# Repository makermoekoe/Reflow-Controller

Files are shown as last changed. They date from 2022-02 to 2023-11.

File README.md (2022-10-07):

# Reflow-Controller

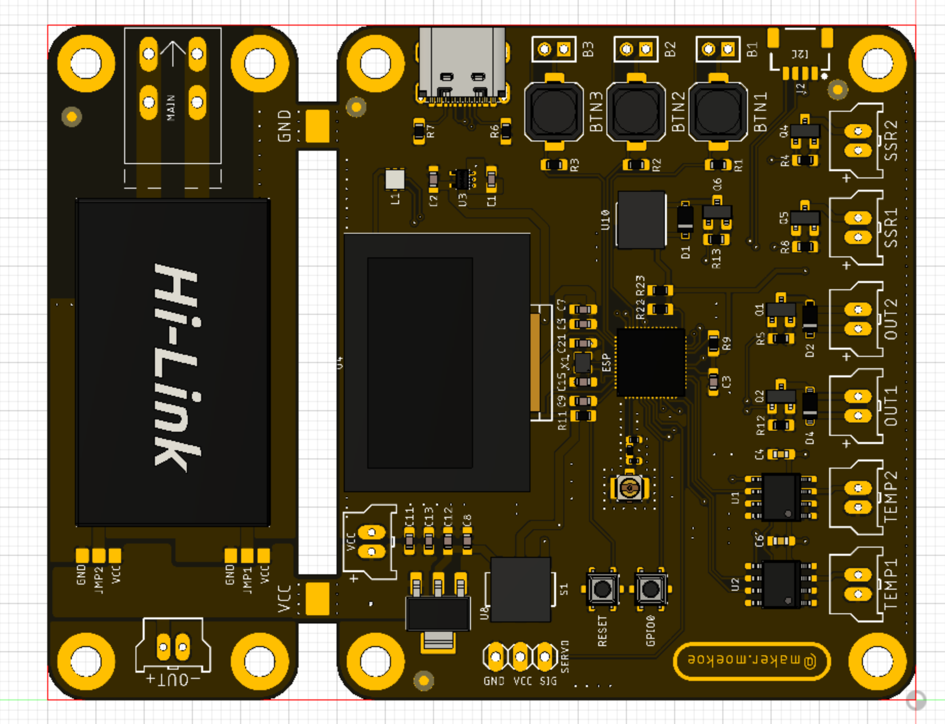
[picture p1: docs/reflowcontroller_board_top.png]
</a>

The Reflow-Controller was built to control different kinds of reflow ovens, hotplates and whatever is coming to my mind in the future. It is based on the ESP32-S2 ([datasheet](https://www.espressif.com/sites/default/files/documentation/esp32-s2_datasheet_en.pdf)) and thus can be programmed to be used with a WiFi App or whatever. Nevertheless, it has an onboard OLED display and three buttons included to be used as a standalone solution either.

The [Youtube video](https://youtu.be/nffLDqJwJ3Q) shows the assembly of a complete reflow oven system and the first tests.

Features of the PCB:

- ESP32-S2 MCU
- 2x MAX6675 thermocouple sensor input
- 2x Fan output (inductive loads/flyback diodes included)
- 2x Solid state relay output
- 3x User button
- 1x APA102 user LED
- 1x Buzzer
- 1x Servo motor output
- 0,96" OLED display
- Optional ACDC converter (HLK-PM05, HLK-PM12) which can be separated if not used
- Optional I2C (QWIIC) connector

## GPIOs

The ESP32-S2 is connected like this:

Function | GPIO | Mode
-------- | -------- | --------
SSR1 | GPIO1 | Output
SSR2 | GPIO2 | Output
Servo | GPIO3 | Output
Fan1 | GPIO5 | Output
Fan2 | GPIO6 | Output
CLK | GPIO7 | SPI
MISO | GPIO9 | SPI
MOSI | GPIO11 | SPI
CS1 | GPIO12 | SPI
CS2 | GPIO13 | SPI
Buzzer | GPIO15 | Output
USB D- | GPIO19 | CDC
USB D+ | GPIO20 | CDC
SDA | GPIO33 | I2C
SCL | GPIO35 | I2C
Button1 | GPIO36 | Input
Button2 | GPIO39 | Input
Button3 | GPIO40 | Input
LED CLK | GPIO37 | LED
LED DATA | GPIO38 | LED
OLED RST | GPIO45 | Output

## ACDC power supply

The upper part of the PCB can be used as a power supply for the whole board as well as the higher voltage outputs (SSRs, Fans). If not used, it can be separated from the main board and may be used in another project where an ACDC adapter is needed.

The main board is equipped with an LM1117 3.3v voltage regulator which can be feed with 15v max. The output voltage of the ACDC power supply is the voltage for the SSR and the fan output channels. If you wanna use a servo motor in your project, make sure that the power supply has the correct voltage for the motor (probably 5v).

The HLK-PMXX module for the upper part of the PCB can be placed in two ways - on the bottom or on the top side. This gives the possibility to mount the whole PCB behind an acrylic glass (or whatever) so that the buttons as well as the OLED display are accessible. The two jumpers can then be used to select which signal is VCC and which one is GND. **Keep in mind that there are high voltage pins on the top side of the PCB when mounting the power supply on the bottom side! I've designed a 3D-printable cover, so that these pins cannot be touched accidentally. (Should be mounted in both cases)**

The board can also be powered via USB-C, but keep in mind that the output channels and the servo motor are not powered in this case (initially it is just available for flashing the board).

## Case & Spacer

As I wanna hide the whole PCB behind an acrylic glass (transparent) I've designed a simple case for the high voltage pins at the top and a spacer at the bottom of the PCB. In the end, the acrylic glass will be laser-cutted with some bridges for the buttons. Distance between PCB and acrylic glass is 5mm.

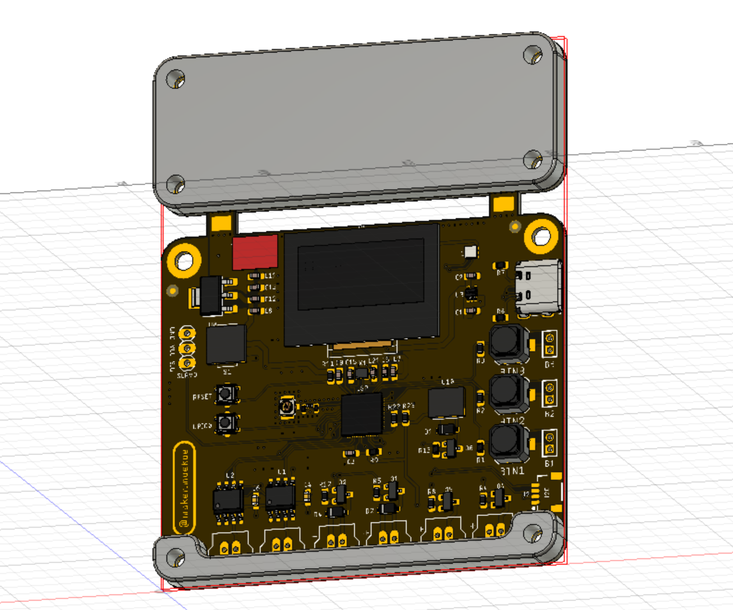
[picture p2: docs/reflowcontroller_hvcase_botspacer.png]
</a>

## Assembled reflow oven

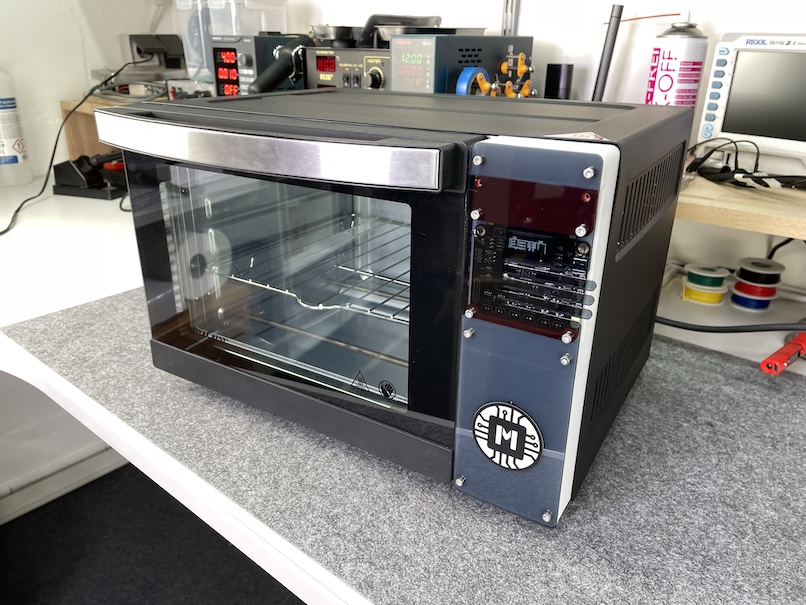
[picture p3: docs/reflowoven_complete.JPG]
</a>

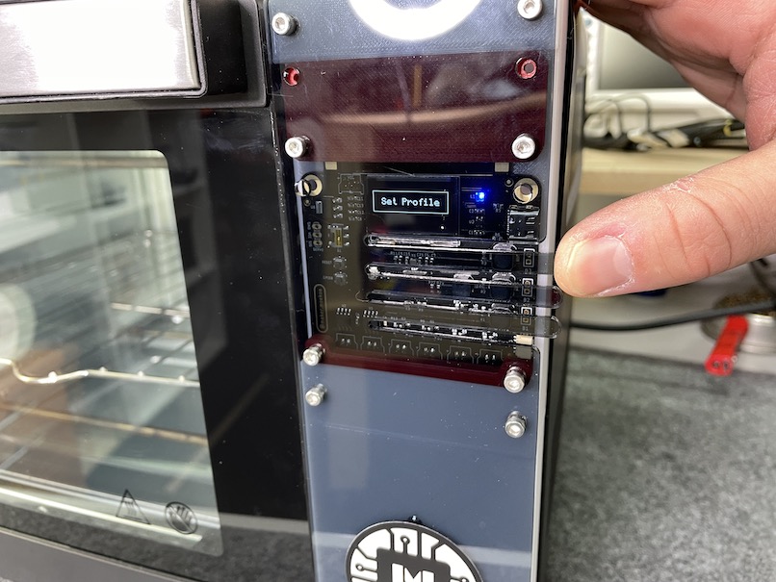
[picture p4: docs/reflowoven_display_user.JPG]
</a>

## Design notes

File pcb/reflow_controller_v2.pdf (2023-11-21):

Comment | Designator | Footprint | Device | Qty Description | Manufacturer | Mfr. Part No. | Supplier | supplier Part number
Connector | -OUT+,OUT1,OUT2,SSR1,SSR2,TEMP1,TEMP2,VCC MOLEX_2MM_2P | MOLEX_2MM_2P | 8 | Molex | 55935-0210 | 538-55935-0210
PIN HEADER | B1,B2,B3 | 1X02M | PINHD-1X02_2.00 | 3 PIN HEADER | XKB Connectivity | X4612WV-02I-C40D28 | LCSC | C2883055
PIN HEADER | SERVO | 1X03 | PINHD-1X03_2.54 | 1 PIN HEADER | XKB Connectivity | X6511WV-03H-C30D60 | LCSC | C706875
Connector | J2 | 1X04_1MM_RA | QWIIC_CONNECTORJS-1MM | 1 SparkFun I2C Standard Qwiic Connector SparkFun | PRT-16766 | Mouser | 474-PRT-16766
Connector | F2,F3 | R0402 | R-EU-0402-WOKEEPOUT | 2
0.1µF | C4,C6 | C0603 | C-EUC0603 | 2 CAPACITOR, European symbol YAGEO | CS0603KRX7R0BB104 | Mouser | 603-CS0603KRX70BB104
0.1µF | C3,C5,C9,C20 | C0603 | C-EU_WO_KEEPOUT | 4 | YAGEO | CS0603KRX7R0BB104 | Mouser | 603-CS0603KRX70BB104
0R-JUMPA | JMP1,JMP2 | A0R-JMP | 0R-JUMPA | 2 SMD 0R 0805 Jumper
10k | R1,R2,R3,R4,R5,R8,R9,R11,R12,R13,R20 | R0603 | R-EU_WO_KEEPOUT | 11 | Panasonic | ERJ-1RHD1002C | Mouser | 667-ERJ-1RHD1002C
10pF | C15,C21 | C0603 | C-EU_WO_KEEPOUT | 2 | YAGEO | CC0603FRNPO0BN100 | Mouser | 603-CC0603FR0BN100
10µF | C1,C7,C8,C13,C17,C18,C19 | C0603 | C-EU_WO_KEEPOUT | 7 | Samsung Electro-MechanicsCL10A106KQ8NNNC | Mouser | 187-CL10A106KQ8NNNC
1µF | C2,C11,C12 | C0603 | C-EU_WO_KEEPOUT | 3 | Taiyo Yuden | TMR107B7105KA-T | Mouser | 963-TMR107B7105KA-T
2.2µF | C14,C16 | C0603 | C-EU_WO_KEEPOUT | 2 | Murata Electronics | GRT188C71E225KE13D | Mouser | 81-GRT188C71E225KE3D
390k | R21 | R0603 | R-EU_WO_KEEPOUT | 1 | Panasonic | ERJ-1RHD3903C | Mouser | 667-ERJ-1RHD3903C
5.1k | R6,R7,R22,R23 | R0603 | R-EU_WO_KEEPOUT | 4 | Panasonic | ERA-1AEB512C | Mouser | 667-ERA-1AEB512C
5.6pF | F1 | R0402 | R-EU-0402-WOKEEPOUT | 1 | Murata Electronics | GJM1555C1H5R6FB01D | Mouser | 81-GJM1555C1H5R6FB1D
APA102_2020 | L1 | APA102_2020 | APA102_2020 | 1 | SparkFun | COM-14608 | Mouser | 474-COM-14608
BUTTON_4PIN_TS-1070A | B4,B5,B6 | BUTTON_WHITE_SMD | BUTTON_4PIN_TS-1070A | 3 | Yuandi | TS-1070A-B3D2 | LCSC | C492879
BUTTON_4PIN_TS_1177 | GPIO0,RESET | TS-1177-C-B-B | BUTTON_4PIN_TS_1177 | 2 | XKB Connectivity | TS-1177-C-B-B | LCSC | C561512
BUTTON_6X6_SILICON | BTN1,BTN2,BTN3 | BUTTON_SILICON | BUTTON_6X6_SILICON | 3 | | | Aliexpress
DIODE_SOD123 | D1,D2,D4 | SOD123 | DIODE_SOD123 | 3 | onsemi / Fairchild | MMSD4448 | Mouser | 512-MMSD4448
ESP32_S2_QFN56_NEW | ESP | QFN56_7X7 | ESP32_S2_QFN56_NEW | 1 | Espressif Systems | ESP32-S2 | Mouser | 356-ESP32-S2
HILINK_PM03 | U11 | HILINK_PM03 | HILINK_PM03 | 1 | | | Aliexpress
IRLML2502 | Q1,Q2,Q4,Q5,Q6 | SOT23 | IRLML2502 | 5 | Infineon / IR | IRLML2502TRPBF | Mouser | 942-IRLML2502TRPBF
LM1117 | U8 | SOT223 | LM1117 | 1 | onsemi | LM1117MPX-18NOPB | Mouser | 863-LM1117MPX-18NOPB
MAX6675 | U1,U2 | SO8 | MAX6675 | 2 | Maxim Integrated | MAX6675ISA+ | | 700-MAX6675ISA
MLT-5030-BUZZER | U10 | MLT-5030-BUZZER | MLT-5030-BUZZER | 1 | | | Aliexpress
OLD_096_SSD1306_30P_2B U4 | OLED_096_30P_B | OLD_096_SSD1306_30P_2B | 1 30 pin 0.96 inch OLED SSD1306 | Aliexpress
RT9193_SC70-5 | U3 | SC-70-5 | RT9193_SC70-5 | 1 | | | Aliexpress
SWITCH_MS-22C01-G010 | S1 | MS-22C01-G010 | SWITCH_MS-22C01-G010 | 1 | Chipmall.com Limited | MS-22C01-G010 | LCSC | MS-22C01-G010
UFL_ANT_CONNECTOR | U$3 | UFL_ANT_CONNECTOR UFL_ANT_CONNECTOR | 1 | Adafruit | 1661 Mouser | 485-1661
USB_C_C393939 | U9 | USBC_C393939 | USB_C_C393939 | 1 | SHOU HAN | TYPE-C16PIN | LCSC | C393939
WAGO_AST045_2 | MAIN | WAGO_AST045_2 | WAGO_AST045_2 | 1
XTAL_2016 | X1 | XTYL_2016 | XTAL_2016 | 1 | Kyocera AVX | CX2016DB40000H0FLJC1 | Mouser | 581-CX2016DB40000HLJ
| | Mouser
| | Aliexpress
| | LCSC
| | Manufacturer
| | Not found!

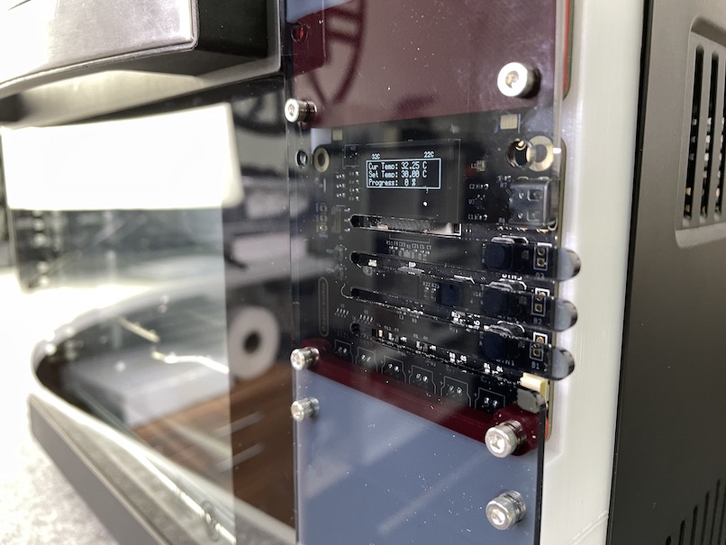
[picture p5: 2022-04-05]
docs/reflowoven_display.JPG

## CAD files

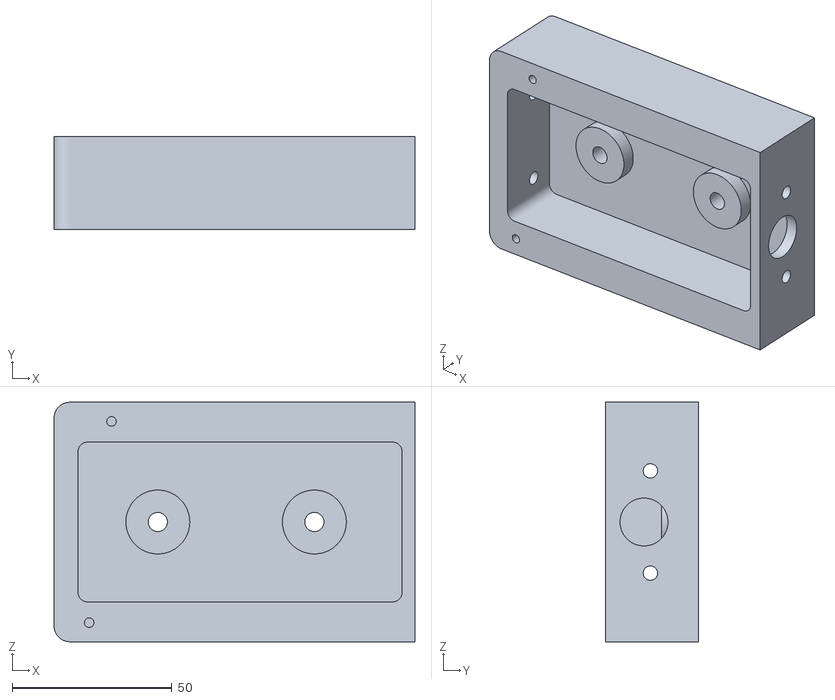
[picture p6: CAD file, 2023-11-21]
case/rc_base1.stl
113.0 x 29.0 x 75.0

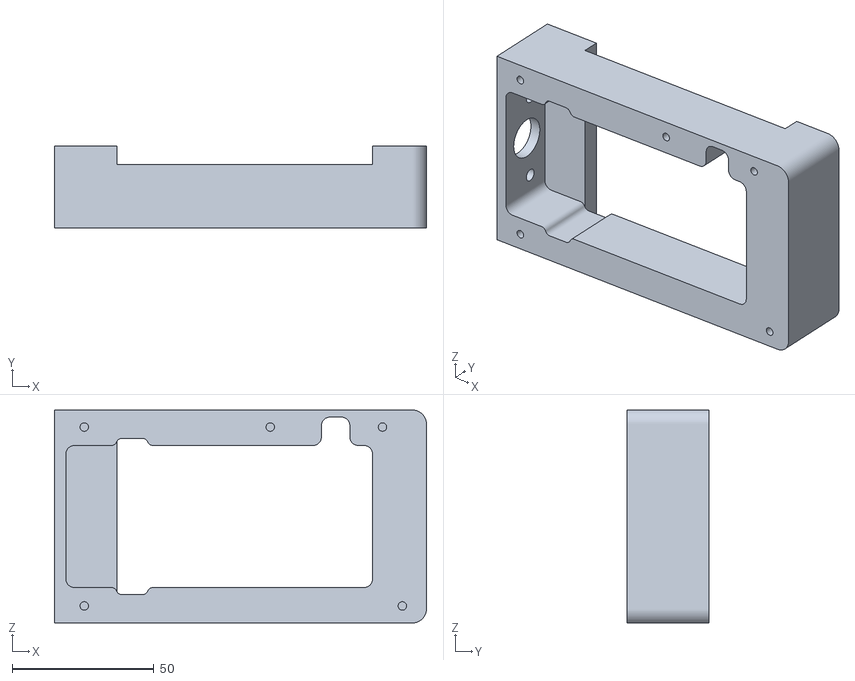
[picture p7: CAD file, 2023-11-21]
case/rc_base2.stl
131.0 x 29.0 x 75.0

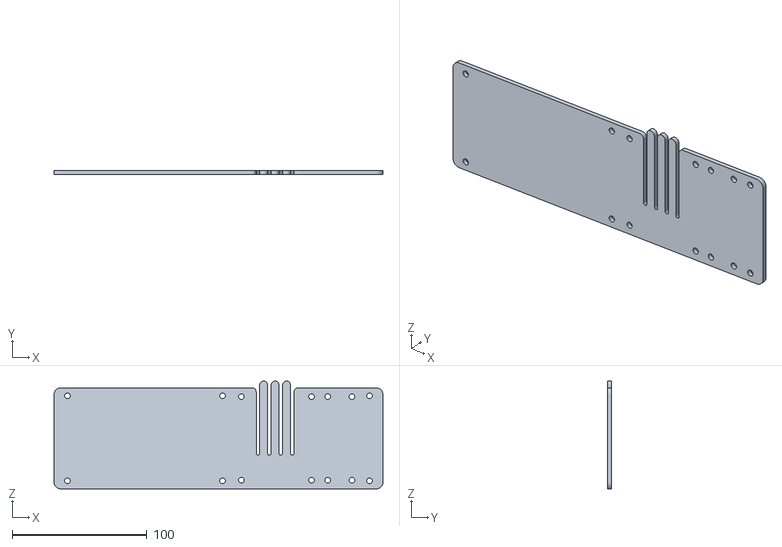
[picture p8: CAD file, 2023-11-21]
case/rc_acrylic_front.stl
244.0 x 3.00 x 80.0

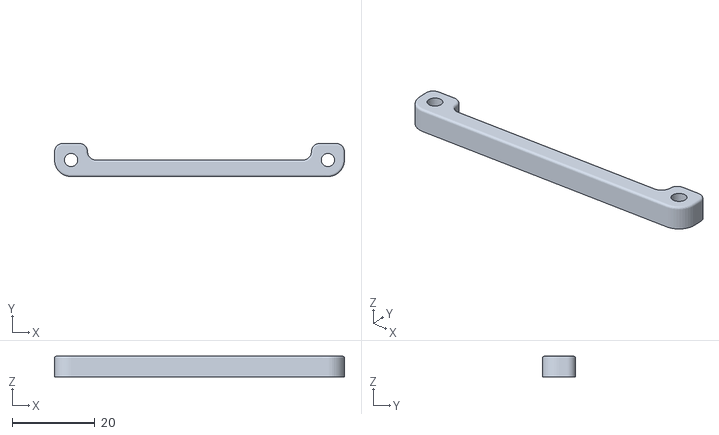
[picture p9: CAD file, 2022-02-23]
case/bot_spacer.stl
70.0 x 8.00 x 5.00

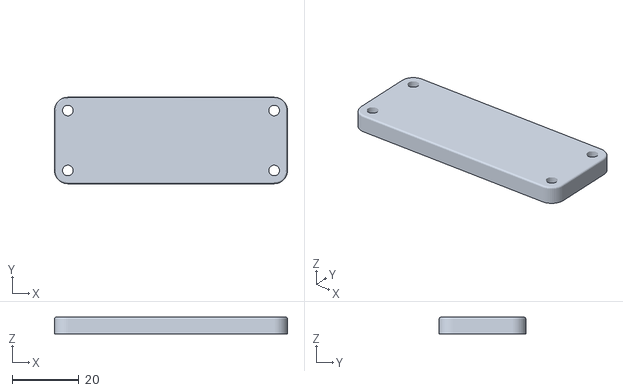
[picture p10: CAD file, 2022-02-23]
case/hv_case.stl
70.0 x 26.0 x 5.00

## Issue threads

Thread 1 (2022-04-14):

BOM and Gerber files

Assistedevolution, 2022-04-14:
Great project and thanks for sharing. I know this is still work in progress but do you have a BOM and maybe Gerber files for this project?
Cheers

factotumindustries, 2022-05-22:
Obviously there is an exportable BoM from Eagle. It isn't quite detailed enough for a complete "shopping list" of parts though...

rgruberski, 2023-02-03:
Hi! Is it possible to get a more detailed components list? Could you share the components list that you have used in the project? The assembly file available in the repo is quite limited. I would like to build it, but it is a little bit tricky to figure out how components should be used. Thank you in advance!

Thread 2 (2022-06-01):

Compiling issue

albimazzu, 2022-06-01:
First of all, thanks for sharing your project. I am struggling to compile the code because is returning this compile error:

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

I tried different configurations editing the platformio.ini file but i'm still stuck..
Here my configuration file:

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

I'm using platformio with core 6.0.1, espressif32@4.4.0

Closed 2023-01-24.

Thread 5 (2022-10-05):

OLED Display

thurstinn, 2022-10-05:
Hey, thanks for the upload. I have designed my own board with your schematics. I have checked and re-checked and I know that everything is correctly routed and assembled. I am using the exact same display with SSD1306 and I have tried 2 now. I have had no issues flashing the chip and the buttons are working causing the RGB to light up accordingly, there is just no image on screen. Unless I actually have received 2 bunk displays in a row, is there possibly anything that I could be missing here? Like I said I have tested the board and the screen is getting power, i2c, and has the exact same topography as far as passives etc. that yours has. Any advice would be appreciated, I have spent a lot of time and money on this project.
P.S. love your YT channel

dayar, 2022-10-05:
Hello,
I have recently been assembling this PCB and testing the code and have had the same problem.
The solution has been to comment out the I2C initialization line before the initialization of the U8G2 drive.
`  // Wire.begin(SDA_PIN, SCL_PIN);
  delay(100);
  u8g2.begin();`
 It seems that the initialization of U8G2 already performs the initialization of the I2C and if both initializations are performed, the OLED screen does not work.
Try to see if it works for you

thurstinn, 2022-10-06:
Unfortunately it is still not working :(

dayar, 2022-10-06:
Try to change OLED Display declaration of U8G2 library to one of these:

`U8G2_SSD1306_128X64_VCOMH0_F_HW_I2C u8g2(U8G2_R0, /* reset=*/ OLED_RST_PIN, /* clock=*/ SCL_PIN, /* data=*/ SDA_PIN);`
`// U8G2_SH1106_128X64_VCOMH0_F_HW_I2C u8g2(U8G2_R0, /* reset=*/ OLED_RST_PIN, /* clock=*/ SCL_PIN, /* data=*/ SDA_PIN);`

thurstinn, 2022-10-06:
No such luck. I ordered a new display that is attached to its own board and will try it using the I2C connector. One other issue I am wondering about is using GPIO 45 as the reset pin. It is a strapping pin and with the pull up resistor it is setting the esp32s2's VDD_SPI to 1.8V on startup. I have the FN4R2 and datasheet says that VDD_SPI needs to be set to 3.3V (GPIO 45 = 0) in order for the embedded flash to work. I'm not sure how vital that is as makermoekoe appears to be using a similar chip version. Either way I appreciate your help and if you have any more suggestions please keep them coming.

dayar, 2022-10-07:
I'm glad it works for you, in my case I had the ESP32-S2FH2 version, without Embedded PSRAM, so the GPIO45 pin doesn't influence me.
Anyway, I'm testing the code and there are some unfinished things or things that don't work completely correctly, you'll see it soon.

thurstinn, 2022-10-07:
Ya I was hoping it would get some updates. I just started learning to code at university so I'm a little lost on software side. Looking forward to seeing what you got.

p1ngb4ck, 2023-01-16:
@thurstinn were you able to solve the issue with the "direct" OLED connection, or only with "external" display via QWIIC connector? The latter would be really bad in my usecase unfortunately - and I have the FN4R2 version of the ESP23-S2 also.
Could you maybe aid me by explaining your findings as exact as possible again for me ?
Sorry to bother you and a thanks so much in advance

p1ngb4ck, 2023-01-24:
nevermind. Got the displays running.
What I realized is :
@dayar : the S2FH2 version has the same dependency on VDD_SPI needs to be set to 3.3V just like the FN4R2 version (which I also have) - you would be affected if that was the errors/problems root cause.

You can burn efuses on the FN4R2 chip version to make it ignore the signal level of the GPIO 45 strapping pin and go for 3.3V on VDD_SPI always. But - this cannot be undone. Use espefuse.py tool for that, I did that successfully but had no actual effect.

If you use any version of the arduino-esp32 framework newer than the one used by makermoekoe (2.00-alpha-1) you will get problems with buzzer, display and led. right now I am investigating.

When researching this - I actually found out, that the displays connection circuit for this pcb was adapted from the adafruit display boards. (see https://cdn-learn.adafruit.com/assets/assets/000/093/884/original/adafruit_products_0-96in_OLED_sch.png)

For me, the display is working, after re-doing the soldering of all connections. Make sure to double check I2C Pins of the ESP32 and all connector-pins and to use visual studio with the exact provided library versions that makermoekoe uses (do NOT modify platformio.ini ! )to make the display work.

thurstinn, 2023-01-24:
Not sure if you still need this but I ended up designing a new board with a new display circuit for a direct connection.  This is the schematic. The reset pin is no longer connected to the esp32 and instead has what looks an auto reset circuit. I referenced the schematic from the external display module I had bought.

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

p1ngb4ck, 2023-01-25:
@thurstinn TY so much - but I actually got it working using the initial direct 30 pins OLED display I got from Aliexpress.
I also just had success with some very (!) minor tweaks, allowing me to use current versions of arduino-esp32 framework, all libraries and everything in Arduino IDE, which makes it much easier to do the ESP32 chip settings - which is important for USB-CDC (serial output) and much other stuff.
Right now working on putting these changes to my fork.

But : THANKS a bunch for that input, I will definitely take your circuit into account and check it out - it may be extremely helpful for my own pcb idea actually ... so be assured I am very thankful for your input <3

thurstinn, 2023-01-25:
No problem good luck on your project! let me know if I can help. I went by the book with my pcb on a 4 layer board. The esp32-s2 hardware design guideline pdf is a great resource.

WainingForests, 2023-12-30:
I'm a bit confused. This seems like a nice project but it seems there's bom related issues to get everything working?

It sounds like I'd specifically need a ESP32-S2FH2?

@thurstinn You mention a new board, any chance you could link to the design files / a repo with a bom, or is it as simple as buy X model version of esp32 chip and use the original repo files?

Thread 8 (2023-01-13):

U3 - RT9193 - BP Pin left floating while datasheet especially states not to do that

p1ngb4ck, 2023-01-13:
Hi !

As the title says. In your schematics, you leave the BP-Pin of IC U3 (RT9193_SC70-5) floating.
If you have a look at the datasheet of the RT9193 (https://www.richtek.com/assets/product_file/RT9193/DS9193-18.pdf), you will find the functional pin description on page 2 stating the following for the BP-Pin :
[quote]Reference Noise Bypass. This pin cannot be floating. Recommended to connect a 22nF or larger
ceramic capacitor between the BP and GND pins.[/quote]
Also, it is stated in the datasheet, how the actual pcb design around those capacitors should be handled for optimal performance (see page 8 of the mentioned datasheet) :
[quote]Bypass Capacitor and Low Noise
Connecting a 22nF between the BP pin and GND pin
significantly reduces noise on the regulator output, it is
critical that the capacitor connection between the BP pin
and GND pin be direct and PCB traces should be as short
as possible. There is a relationship between the bypass
capacitor value and the LDO regulator turn on time. DC
leakage on this pin can affect the LDO regulator output
noise and voltage regulation performance.[/quote]

But, rather than applying those changes, I propse a different approach :

As the RT9193 is hart to get in SC-70-5 packaging, I was actually looking for a direct replacement and found the SC573V33RTRC (available on mouser an others) that "should" (waiting for delivery of some other parts, so I can finally make & test the project) work as a direct replacement.
Advantage of that would be, that it is pin-compatible, is available .. and - doesn`t have a BP-Pin at all but just a 2nd gnd pin in its place - so with your current schematics, you would just leave that 2nd ground pin floating, which shouldn`t be a problem at all.

Thanks so much for all your work though, looking forward to build it =) !!!

makermoekoe, 2023-01-27:
I think the words "cannot be floating" should mean that it "shouldn't be floating", because actually it works with leaving it floating.
Regarding the block diagram in the RT9193 datasheet, it is just to stabilize the reference voltage for the comparator and thus (as the datasheet says as well) is just to reduce the noise on the output voltage. Seems like the unstabilized output voltage is good enough for this use case, but of course the 22nF cap should be placed within the next revision.
Furthermore the SC573V33RTRC seems to be a good alternative for this revision.

p1ngb4ck, 2023-01-27:
Yes you are absolutely right with shouldnt instead of cannot, I am sorry
Thanks so much for coming back on this topic and many many thanks for the in general awesome project.
Meanwhile I was able to successfully build it. So I can confirm the SC573V33RTRC is working in general - but it does not support enough power for wifi (at least during my testing).
In the meantime, I managed to get you code running on latest lib and framework versions (just very minor changes necessary) and I was able to add basic wifi and ota flashing.
I think this will be useful for ongoing developement, while having the board already installed to the oven. My goal is to  implement further wifi control (and temp-curve-modification/preset saving) via webserver on esp and sigrok.
Wifi and OTA already work, now going on to adding the actual wifi controls.
Thank you so much and please dont see this as criticism - the opposite is true indeed. I think this is such a nice project, that it is more than worth to invest my time into and I hope it is in your interest also, to see this being actively developed on =)

choleaoum, 2023-05-27:
> SC573V33RTRC

> So I can confirm the SC573V33RTRC is working in general - but it does not support enough power for wifi (at least during my testing).

I can't find the R9193 available anywhere and the SC573 is not recommended for new design. Do you think RT9013-33GU5 would work and have enough power to support WiFI?

I also wanted to say thanks for your fork.

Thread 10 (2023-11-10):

Add printed parts and dxf for lasercut acrylic

HiddenTr0ll, 2023-11-10:
Hello @makermoekoe ,
I am building your wonderful controller at the moment and noticed, that you haven't uploaded the 3D-Printed files or the file to lasercut the transparent acrylic sheet.

These would help me out tremendously, as I have the exact same LIDL oven as you do.

Many thanks in advance!

makermoekoe, 2023-11-21:
Sorry for the late response! I have just added all the 3D models

Closed 2023-11-21.

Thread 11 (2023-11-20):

PDF schematics

ilium007, 2023-11-20:
Great project - any chance of uploading PDF schematics for the project? KiCad user...

makermoekoe, 2023-11-21:
[Added](https://github.com/makermoekoe/Reflow-Controller/blob/main/pcb/reflow_controller_v2_schematics.pdf)!

ilium007, 2023-11-21:
Thanks so much!

Closed 2023-11-21.

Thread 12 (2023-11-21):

Mention what Thermocouple you use

HiddenTr0ll, 2023-11-21:
Hello,
I have the exact same setup as you did in your video, but my meassured temperature lags behind significantly.
My best guess is, that my thermocouple takes way to long to meassure the actual temperature because when i meassure with a laser theermometer the temperature is even higher than the set temp.

I hope you have a link or maybe another idea!

Quas7, 2024-01-29:
Maybe you share, what type you currently use? A small K-type thermocouple glued to a piece of FR4 is my reference probe.
Also note, that the reflective metal is not ideal (not a black body radiator) to be measured with non-contact IR thermometers but it should be lower not higher in temperature reading.

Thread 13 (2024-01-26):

Documentation enhancement: ESP32-S2Fxx is required not ESP32-S2

Quas7, 2024-01-26:
I ordered an esp32-s2 without thinking much about it but after not being able to flash the chip at all I transfered another "S2" from a dev board. That fixed the issue for me.

Out of curiostiy I moved my ordered "S2" to the dev board - flashing was not possible. Another one from the ordered batch did not work either. I almost started doubting my solderin skills.
But later a colleague hinted that Espressif might have done some "extensions" to their portfolio (see [Datasheet](https://www.espressif.com/sites/default/files/documentation/esp32-s2_datasheet_en.pdf)). And of course they did:
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

The ESP32-S2 has no flash embedded at all and a little correction of the BOM might be a good idea to include the S2F.

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

HappyTechnician, 2024-03-30:
I ordered the same.. Just now re-ordered the S2FH4

HappyTechnician, 2024-05-06:
I have found that the LM1117MPX_18NOPB is a 1.8V regulator.. Is that the correct regulator? The schematic shows 3.3V forth switch positions..

Quas7, 2024-05-06:
I used a 3.3V I had at hand with some pin bending. 1.8V does not make much sense for a 3.3V uController.

Would be good to add one or two  footprints in parallel to have at least two standard formfactors for the LDO to chose from.

HappyTechnician, 2024-05-06:
Yeah, I'll change that out and see what else is awkward with it

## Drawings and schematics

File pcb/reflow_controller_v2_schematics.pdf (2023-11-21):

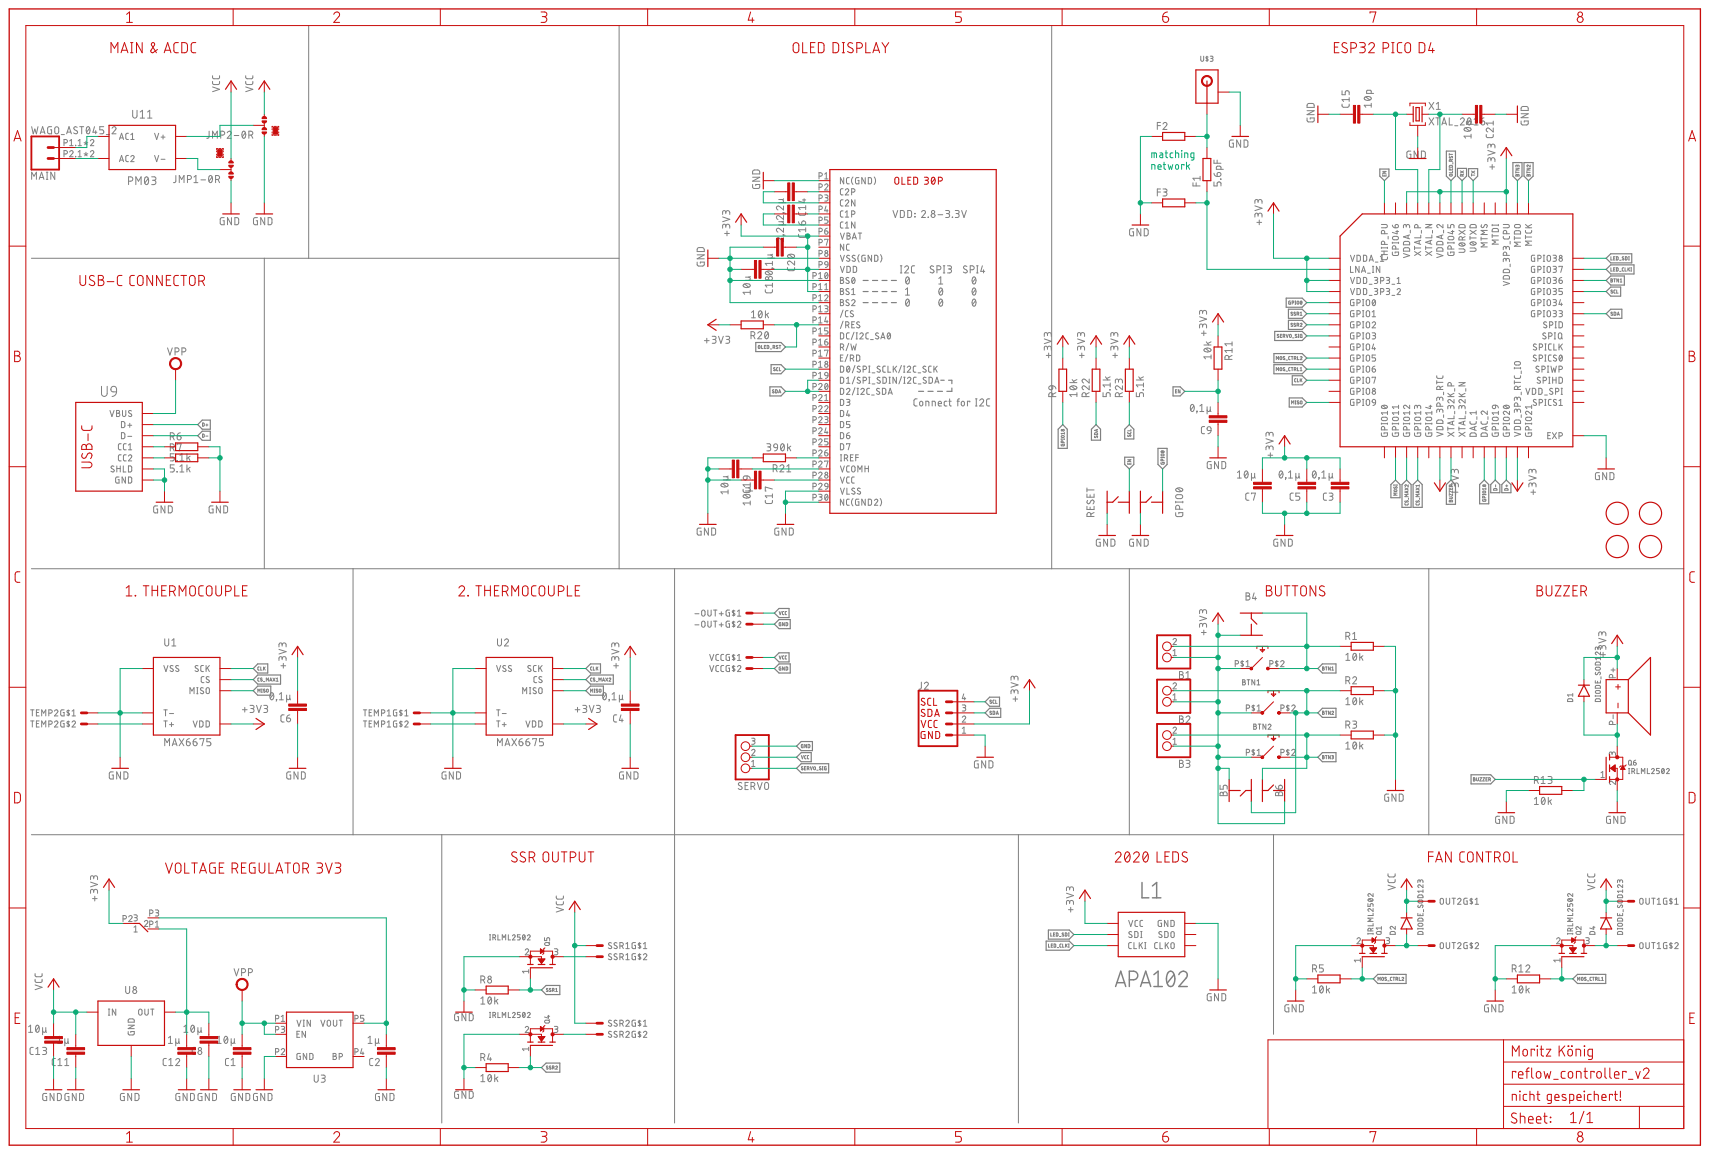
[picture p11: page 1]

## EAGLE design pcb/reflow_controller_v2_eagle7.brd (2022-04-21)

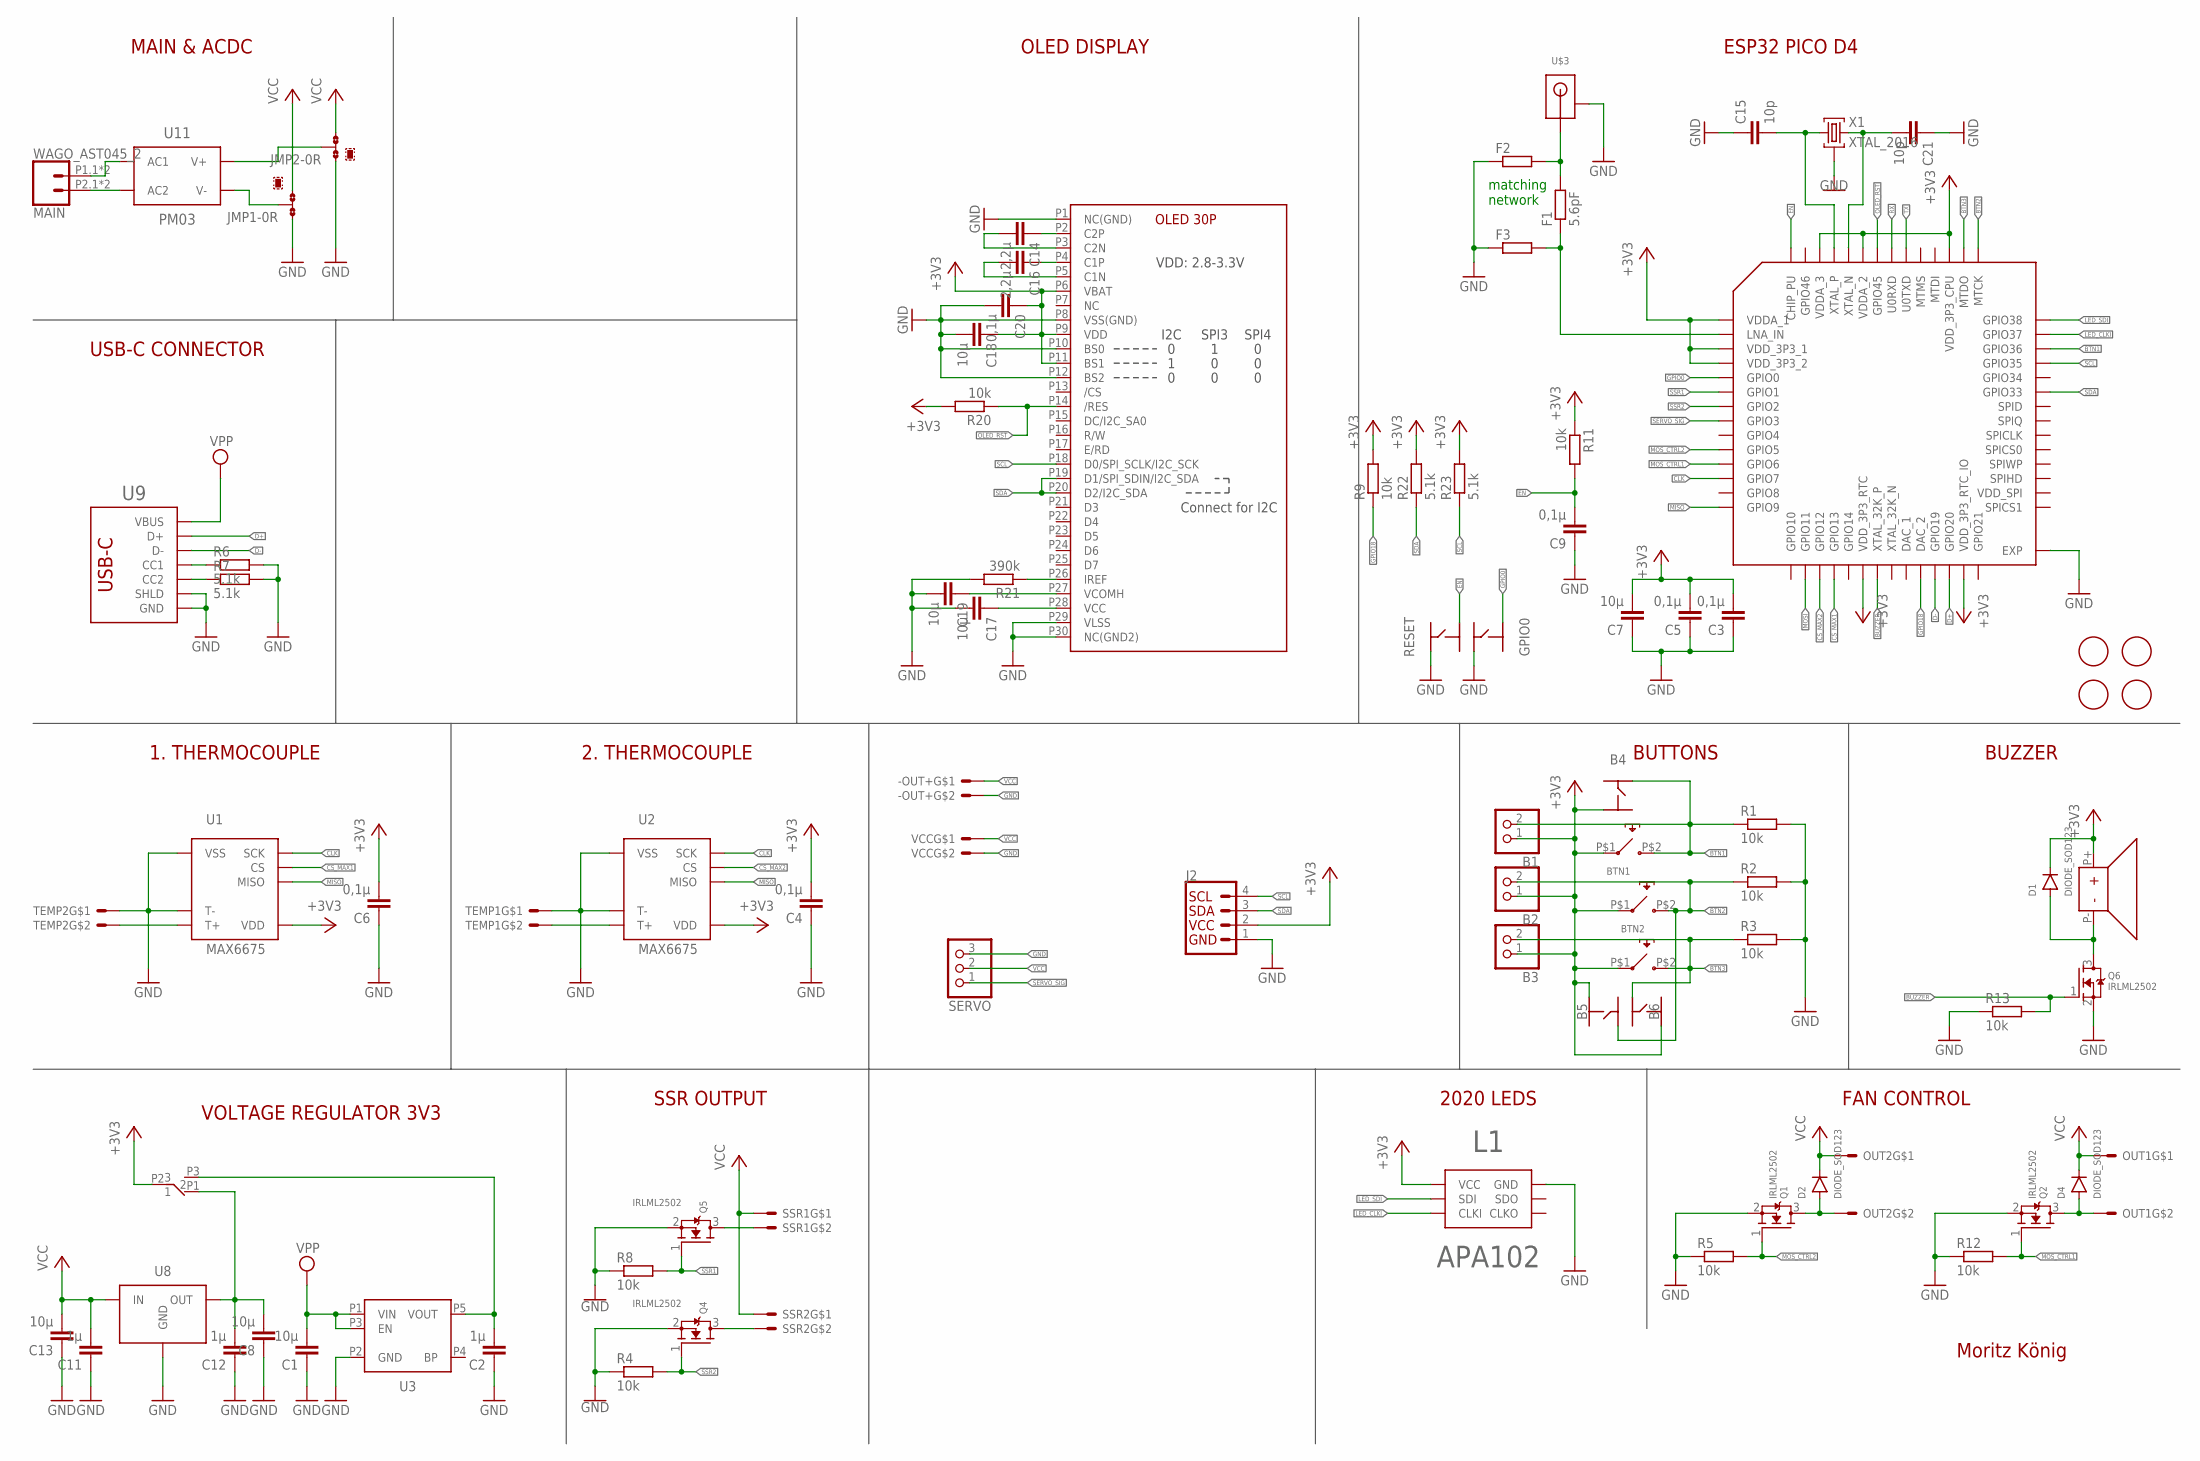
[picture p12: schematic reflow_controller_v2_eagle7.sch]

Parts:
-OUT+: MOLEX_2MM_2P
B1, B2, B3: PINHD-1X02_2.00; 1X02M
B4, B5, B6: BUTTON_4PIN_TS-1070A; BUTTON_WHITE_SMD
BTN1, BTN2, BTN3: BUTTON_6X6_SILICON; BUTTON_SILICON
C1, C7, C8, C13, C17, C18, C19: 10µ; C0603
C2, C11, C12: 1µ; C0603
C3, C4, C5, C6, C9, C20: 0,1µ; C0603
C14, C16: 2,2µ; C0603
C15, C21: 10p; C0603
D1, D2, D4: DIODE_SOD123; SOD123
ESP: ESP32_S2_QFN56_NEW; QFN56_7X7
F1: 5.6pF; R0402
F2, F3: R-EU-0402-WOKEEPOUT; R0402
GPIO0: BUTTON_4PIN_TS_1177; TS-1177-C-B-B
J2: QWIIC_CONNECTORJS-1MM; 1X04_1MM_RA
JMP1, JMP2: 0R-JUMPA; A0R-JMP
L1: APA102_2020
MAIN: WAGO_AST045_2
OUT1, OUT2: MOLEX_2MM_2P
Q1, Q2, Q4, Q5, Q6: IRLML2502; SOT23
R1, R2, R3, R4, R5, R8, R9, R11, R12, R13, R20: 10k; R0603
R6, R7, R22, R23: 5.1k; R0603
R21: 390k; R0603
RESET: BUTTON_4PIN_TS_1177; TS-1177-C-B-B
S1: SWITCH_MS-22C01-G010; MS-22C01-G010
SERVO: PINHD-1X03_2.54; 1X03
SSR1, SSR2: MOLEX_2MM_2P
TEMP1, TEMP2: MOLEX_2MM_2P
U1, U2: MAX6675; SO8
U3: RT9193_SC70-5; SC-70-5
U4: OLD_096_SSD1306_30P_2B; OLED_096_30P_B
U8: LM1117; SOT223
U9: USB_C_C393939; USBC_C393939
U10: MLT-5030-BUZZER
U11: HILINK_PM03
U$1, U$2, U$4, U$5: FIDUCIAL; FIDUCIAL_1MM
U$3: UFL_ANT_CONNECTOR
VCC: MOLEX_2MM_2P
X1: XTAL_2016; XTYL_2016

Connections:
+3V3: B1.1, B2.1, B3.1, B4.P$2 (3), B5.P$2 (3), B6.P$2 (3), BTN1.P$1 (P1), BTN2.P$1 (P1), BTN3.P$1 (P1), C3.2, C4.2, C5.2, C6.2, C7.2, C18.1, C20.1, D1.P$2 (C), ESP.1 (VDDA_1), ESP.3 (VDD_3P3_1), ESP.4 (VDD_3P3_2), ESP.20 (VDD_3P3_RTC), ESP.27 (VDD_3P3_RTC_IO), ESP.45 (VDD_3P3_CPU), ESP.51 (VDDA_2), ESP.54 (VDDA_3), J2.2 (VCC), L1.P1 (VCC), L1.P1.1 (VCC), R9.2, R11.1, R20.2, R22.2, R23.2, S1.P2 (2), U1.4 (VDD), U2.4 (VDD), U4.P6 (VBAT), U4.P9 (VDD), U4.P11 (BS1), U10.P+
ANTENNA1: F1.2, F2.2, U$3.ANT
BTN1: B1.2, B4.P$4 (2), BTN1.P$2 (P2), ESP.40 (GPIO36), R1.1
BTN2: B2.2, B5.P$4 (2), BTN2.P$2 (P2), ESP.43 (MTCK), R2.1
BTN3: B3.2, B6.P$4 (2), BTN3.P$2 (P2), ESP.44 (MTDO), R3.1
BUZZER: ESP.21 (XTAL_32K_P), Q6.1 (G), R13.2
CLK: ESP.12 (GPIO7), U1.5 (SCK), U2.5 (SCK)
CS_MAX1: ESP.18 (GPIO13), U1.6 (CS)
CS_MAX2: ESP.17 (GPIO12), U2.6 (CS)
D+: ESP.26 (GPIO20), U9.A6 (D+), U9.B6 (D+)
D-: ESP.25 (GPIO19), U9.A7 (D-), U9.B7 (D-)
EN: C9.2, ESP.56 (CHIP_PU), R11.2, RESET.P4 (4)
GND: -OUT+.2, C1.1, C2.1, C3.1, C4.1, C5.1, C6.1, C7.1, C8.1, C9.1, C11.1, C12.1, C13.1, C15.1, C17.2, C18.2, C19.2, C20.2, C21.1, ESP.57 (EXP), F2.1, F3.1, GPIO0.P1 (1), J2.1 (GND), JMP1.1, JMP2.1, L1.P6 (GND), L1.P6.1 (GND), Q1.2 (S), Q2.2 (S), Q4.2 (S), Q5.2 (S), Q6.2 (S), R1.2, R2.2, R3.2, R4.1, R5.1, R6.2, R7.2, R8.1, R12.1, R13.1, R21.2, RESET.P1 (1), SERVO.3, TEMP1.1, TEMP2.1, U1.1 (VSS), U1.2 (T-), U2.1 (VSS), U2.2 (T-), U3.P2 (GND), U4.P1 (NC(GND)), U4.P8 (VSS(GND)), U4.P10 (BS0), U4.P12 (BS2), U4.P29 (VLSS), U4.P30 (NC(GND2)), U8.1 (GND), U9.A1B12 (GND), U9.B1A12 (GND), U9.S1 (SHLD), U9.S2 (SHLD), U9.S3 (SHLD), U9.S4 (SHLD), U$3.P1.- (GND), U$3.P2.- (GND), VCC.2, X1.P2 (G), X1.P4 (G)
GPIO0: ESP.5 (GPIO0), GPIO0.P4 (4)
GPIO18: ESP.24 (DAC_2), R9.1
LED_CLKI: ESP.41 (GPIO37), L1.P5 (CLKI)
LED_SDI: ESP.42 (GPIO38), L1.P4 (SDI)
MISO: ESP.14 (GPIO9), U1.7 (MISO), U2.7 (MISO)
MOSI: ESP.16 (GPIO11)
MOS_CTRL1: ESP.11 (GPIO6), Q2.1 (G), R12.2
MOS_CTRL2: ESP.10 (GPIO5), Q1.1 (G), R5.2
unnamed: MAIN.P1.1 (1), MAIN.P1.2 (1), U11.AC1
unnamed: TEMP2.2, U1.3 (T+)
unnamed: MAIN.P2.1 (2), MAIN.P2.2 (2), U11.AC2
unnamed: ESP.2 (LNA_IN), F1.1, F3.2
unnamed: D2.P$1 (A), OUT2.2, Q1.3 (D)
unnamed: D1.P$1 (A), Q6.3 (D), U10.P-
unnamed: D4.P$1 (A), OUT1.2, Q2.3 (D)
unnamed: Q4.3 (D), SSR2.2
unnamed: Q5.3 (D), SSR1.2
unnamed: C15.2, ESP.53 (XTAL_P), X1.P1 (1)
unnamed: C21.2, ESP.52 (XTAL_N), X1.P3 (2)
unnamed: TEMP1.2, U2.3 (T+)
unnamed: JMP2.2, U11.V+
unnamed: C8.2, C12.2, S1.P1 (1), U8.2 (OUT), U8.4 (OUT)
unnamed: C14.1, U4.P2 (C2P)
unnamed: R7.1, U9.B5 (CC2)
unnamed: C14.2, U4.P3 (C2N)
unnamed: C16.2, U4.P5 (C1N)
unnamed: R21.1, U4.P26 (IREF)
unnamed: C2.2, S1.P3 (3), U3.P5 (VOUT)
unnamed: JMP1.2, U11.V-
unnamed: R6.1, U9.A5 (CC1)
unnamed: C16.1, U4.P4 (C1P)
unnamed: C17.1, U4.P28 (VCC)
unnamed: C19.1, U4.P27 (VCOMH)
OLED_RST: ESP.50 (GPIO45), R20.1, U4.P14 (/RES)
RX: ESP.49 (U0RXD)
SCL: ESP.39 (GPIO35), J2.4 (SCL), R23.1, U4.P18 (D0/SPI_SCLK/I2C_SCK)
SDA: ESP.37 (GPIO33), J2.3 (SDA), R22.1, U4.P19 (D1/SPI_SDIN/I2C_SDA), U4.P20 (D2/I2C_SDA)
SERVO_SIG: ESP.8 (GPIO3), SERVO.1
SSR1: ESP.6 (GPIO1), Q5.1 (G), R8.2
SSR2: ESP.7 (GPIO2), Q4.1 (G), R4.2
TX: ESP.48 (U0TXD)
VCC: -OUT+.1, C11.2, C13.2, D2.P$2 (C), D4.P$2 (C), JMP1.3, JMP2.3, OUT1.1, OUT2.1, SERVO.2, SSR1.1, SSR2.1, U8.3 (IN), VCC.1
VPP: C1.2, U3.P1 (VIN), U3.P3 (EN), U9.A4B9 (VBUS), U9.B4A9 (VBUS)

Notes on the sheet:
Moritz König
VOLTAGE REGULATOR 3V3
2020 LEDS
ESP32 PICO D4
matching network
OLED DISPLAY
USB-C CONNECTOR
MAIN & ACDC
1. THERMOCOUPLE
2. THERMOCOUPLE
BUTTONS
BUZZER
FAN CONTROL
SSR OUTPUT

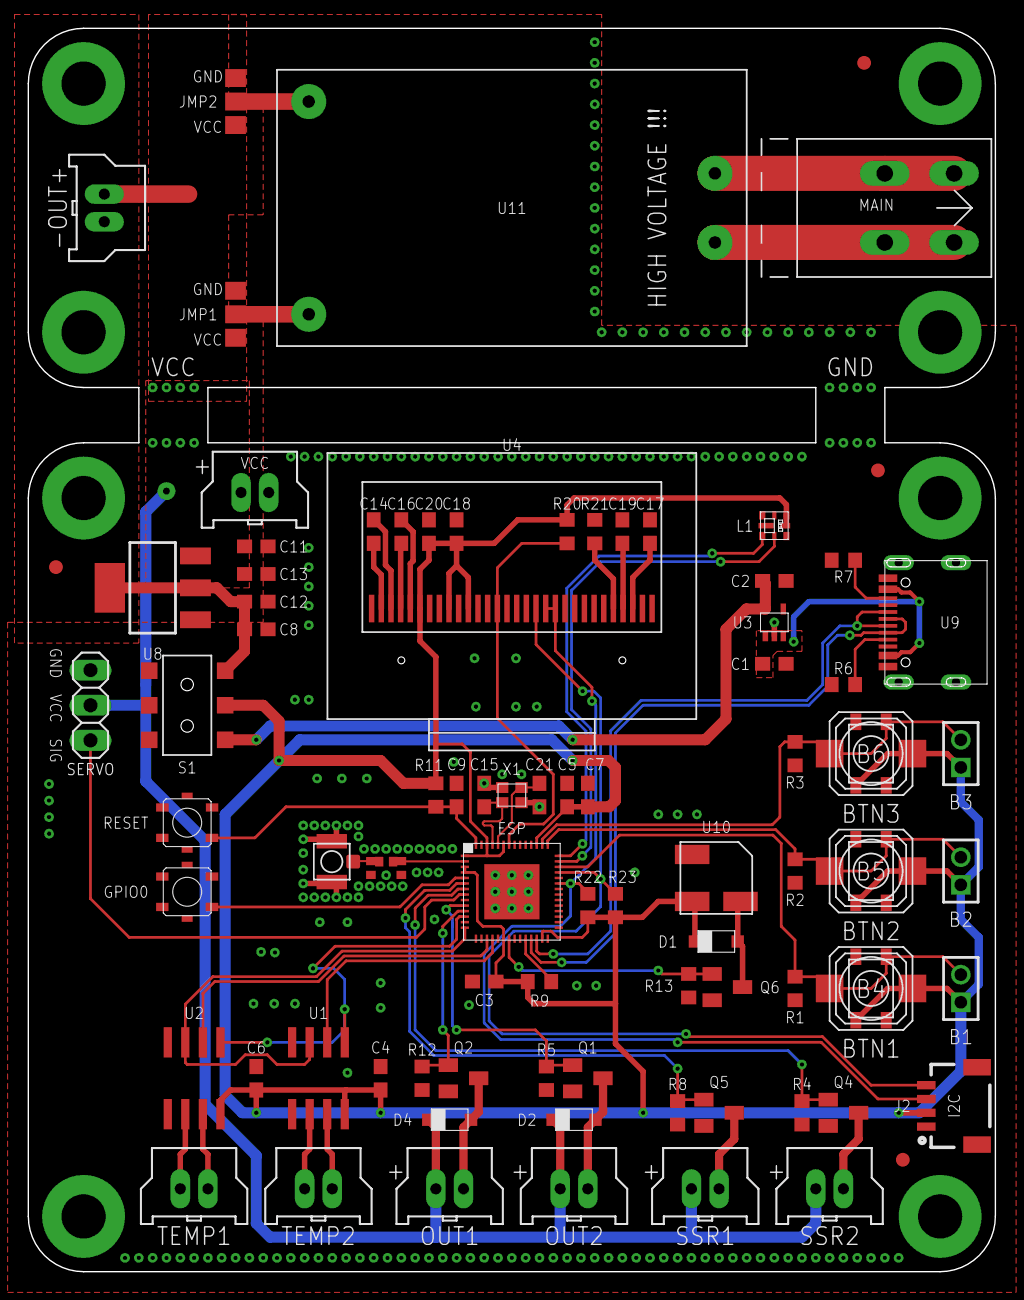
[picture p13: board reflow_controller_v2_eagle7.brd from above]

Board: 2 copper layers, 70.0 x 90.0 mm, 88 parts (0 on the bottom side), 53 nets.

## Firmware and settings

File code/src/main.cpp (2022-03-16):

#include <Arduino.h>
#include <FastLED.h>
#include <Wire.h>
#include <U8g2lib.h>
#include <max6675.h>
#include <Smoothed.h>
#include <Preferences.h>
#include <PID_v1.h>

#define SDA_PIN         33
#define SCL_PIN         35
#define APA102_SDI_PIN  38
#define APA102_CLK_PIN  37
#define OLED_RST_PIN    45
#define CS_MAX1_PIN     13
#define CS_MAX2_PIN     12
#define MISO_PIN        9
#define MOSI_PIN        11
#define CLK_PIN         7

#define MOS_CTRL1_PIN   5
#define MOS_CTRL2_PIN   6
#define SSR1_PIN        1
#define SSR2_PIN        2
#define SERVO_PIN       3
#define BUZZER_PIN      15
#define BTN1_PIN        36
#define BTN2_PIN        39
#define BTN3_PIN        40


#define NUM_LEDS        1
CRGB leds[NUM_LEDS];

#define WIDTH 128
#define HEIGHT 64
U8G2_SSD1306_128X64_NONAME_F_HW_I2C u8g2(U8G2_R0, /* reset=*/ OLED_RST_PIN, /* clock=*/ SCL_PIN, /* data=*/ SDA_PIN);

double pid_setpoint, pid_input, pid_output;
double Kp = 25, Ki = 0.3, Kd = 0.05;
double Kpr = 50, Kir = 0.1, Kdr = 0;
PID pid(&pid_input, &pid_output, &pid_setpoint, Kp, Ki, Kd, DIRECT);
PID pid_reflow(&pid_input, &pid_output, &pid_setpoint, Kpr, Kir, Kdr, DIRECT);


int dutyCycle = 100;

const int PWMFreq = 20000;                                //50hz
const int PWMChannel = 0;
const int PWMResolution = 10;                       //12 bits 0-4095


MAX6675 thermocouple1(CLK_PIN, CS_MAX2_PIN, MISO_PIN);
MAX6675 thermocouple2(CLK_PIN, CS_MAX1_PIN, MISO_PIN);

float current_temperature1 = 0.0;
float current_temperature2 = 0.0;

float pwm_out1 = 0.0;
float pwm_out2 = 0.0;

bool running_reflow = false;
bool init_reflow = false;

bool running_const = false;
bool init_const = false;

bool rampup_reflow = true;
bool rampup_const = true;
bool rampup_const_close = true;
bool preheat_done = false;
bool reflow_done = false;
bool buzzer_state = true;



// Soldering profile
float temperature_setpoint_reflow = 0.0;
float temperature_setpoint_const = 100.0;

float temperature_off = 30.0;
float temperature_soak1 = 150.0;
float temperature_soak2 = 160.0;
float temperature_reflow = 220.0;
float temperature_cooling = 210.0;

int profile_counter = 0;
Preferences preferences;

// int temp_reflow_profile1[] = {
//   30,31,32,33,34,35,36,37,38,39,40,41,42,43,44,45,46,47,48,49,50,51,52,53,54,55,56,57,58,59,60,61,62,63,64,65,66,67,68,69,70,71,72,73,74,75,76,77,
//   78,79,80,81,82,83,84,85,86,87,88,89,90,91,92,93,94,95,96,97,98,99,100,101,102,103,104,105,106,107,108,109,110,111,112,113,114,115,116,117,118,119,
//   120,121,122,123,124,125,126,127,128,129,130,131,132,133,134,135,136,137,138,139,140,141,142,143,144,145,146,147,148,149,150,150,150,150,150,150,150,
//   150,150,150,150,150,150,150,150,150,150,150,150,150,150,150,150,150,150,150,150,150,150,150,150,150,150,150,150,150,150,150,150,150,150,150,150,
//   150,150,150,150,150,150,150,150,150,150,150,150,150,150,150,150,150,150,150,150,150,150,150,150,150,150,150,150,150,150,150,150,150,150,150,150,
//   150,150,151,152,153,154,155,156,157,158,159,160,161,162,163,164,165,166,167,168,169,170,171,172,173,174,175,176,177,178,179,180,181,182,183,184,
//   185,186,187,188,189,190,191,192,193,194,195,196,197,198,199,200,201,202,203,204,205,206,207,208,209,210,211,211,212,212,213,213,214,214,215,215,
//   216,216,217,217,218,218,219,219,220,220,219,218,217,216,215,214,213,212,211,210,209,208,207,206,205,204,203,202,201,200,
// };

#define N_PROFILES    10.0
float selected_profile = 0.0;
float profile_temp[10][10]; // initial, soak1, soak2, reflow, cooling
float profile_time[] = {0.0, 120.0, 200.0, 260.0, 300.0};

int temp_reflow_individual[300];

void store_profile(){
  String key = "profile" + String(int(selected_profile)) + "_";
  preferences.putFloat((key + "soak1").c_str(), temperature_soak1);
  preferences.putFloat((key + "soak2").c_str(), temperature_soak2);
  preferences.putFloat((key + "reflow").c_str(), temperature_reflow);
  preferences.putFloat((key + "cooling").c_str(), temperature_cooling);
}

void read_all_profiles(){
  // preferences.putFloat((name + "_0").c_str(), acs_offset_zero);
  for(int i=0; i<int(N_PROFILES); i++){
    String key = "profile" + String(i) + "_";
    profile_temp[i][1] = preferences.getFloat((key + "soak1").c_str());
    profile_temp[i][2] = preferences.getFloat((key + "soak2").c_str());
    profile_temp[i][3] = preferences.getFloat((key + "reflow").c_str());
    profile_temp[i][4] = preferences.getFloat((key + "cooling").c_str());
  }
}

void calculate_profile_individual(){
  profile_temp[int(selected_profile)][0] = temperature_off;
  profile_temp[int(selected_profile)][1] = temperature_soak1;
  profile_temp[int(selected_profile)][2] = temperature_soak2;
  profile_temp[int(selected_profile)][3] = temperature_reflow;
  profile_temp[int(selected_profile)][4] = temperature_cooling;

  store_profile();

  for(int i=0; i<300; i++){
    if(i >= profile_time[3]) temp_reflow_individual[i] = (profile_temp[int(selected_profile)][4]-profile_temp[int(selected_profile)][3])/(profile_time[4]-profile_time[3]) * (i-profile_time[3]) + profile_temp[int(selected_profile)][3];
    else if(i >= profile_time[2]) temp_reflow_individual[i] = (profile_temp[int(selected_profile)][3]-profile_temp[int(selected_profile)][2])/(profile_time[3]-profile_time[2]) * (i-profile_time[2]) + profile_temp[int(selected_profile)][2];
    else if(i >= profile_time[1]) temp_reflow_individual[i] = (profile_temp[int(selected_profile)][2]-profile_temp[int(selected_profile)][1])/(profile_time[2]-profile_time[1]) * (i-profile_time[1]) + profile_temp[int(selected_profile)][1];
    else if(i >= profile_time[0]) temp_reflow_individual[i] = (profile_temp[int(selected_profile)][1]-profile_temp[int(selected_profile)][0])/(profile_time[1]-profile_time[0]) * (i-profile_time[0]) + profile_temp[int(selected_profile)][0];
  }
}


// Set used fonts with width and height of each character
struct fonts {
  const uint8_t* font;
  int width;
  int height;
};

fonts font_xl = {u8g2_font_profont29_mf, 16, 19};
fonts font_m = {u8g2_font_profont17_mf, 9, 11};
fonts font_s = {u8g2_font_profont12_mf, 6, 8};
fonts font_xs = {u8g2_font_profont10_mf, 5, 6};

// Custom type to set up a page on the OLED display. Baisc structure is a page of three fields.
// A top one with the power, a left one with the voltage and a right one with the current.
struct display_page {
  String title;
  float *value;
  String msg;
  bool is_value;
};

struct display_page_int {
  String title;
  int *value;
  String msg;
  bool is_value;
};

float val1 = 0.0;
float placeholder = 0.0;
String msg2display_top = "";
String msg2display_bot = "";

display_page page_start_reflow = {"Start Reflow", &placeholder, "Start Reflow", false};
display_page page_start_const = {"Start Const", &placeholder, "Start Const", false};
display_page page_select_profile = {"Set Profile", &selected_profile, "", true};
display_page page_const_temp = {"Const Temp", &temperature_setpoint_const, "", true};
display_page page_reflow_temp = {"Reflow Temp", &temperature_reflow, "", true};
display_page page_soak1_temp = {"Soak1 Temp", &temperature_soak1, "", true};
display_page page_soak2_temp = {"Soak2 Temp", &temperature_soak2, "", true};
display_page page_cooling_temp = {"Cooling Temp", &temperature_cooling, "", true};
display_page page_manual_out1 = {"Set PWM1", &pwm_out1, "", true};
display_page page_manual_out2 = {"Set PWM2", &pwm_out2, "", true};

// Menu and Pages
#define N_PAGES 10
int current_page = 0;
bool new_page = true;
unsigned long t_new_page = 0;

struct page {
  int p;
  display_page &page;
};

page pages[N_PAGES] = {
  {0, page_start_reflow},
  {1, page_select_profile},
  {2, page_start_const},
  {3, page_soak1_temp},
  {4, page_soak2_temp},
  {5, page_reflow_temp},
  {6, page_cooling_temp},
  {7, page_const_temp},
  {8, page_manual_out1},
  {9, page_manual_out2},
};

// Alignment for the OLED display
enum box_alignment {
  Center,
  Left,
  Right
};

// Custom type for setting up a box which can be drawn to the oled display. It is defined by
// the top left corner and the width and height of the box.
struct box {
  int32_t left, top, width, height;
  int32_t radius;
  bool has_frame;

  void draw(bool fill) {
    int frame = has_frame ? 4 : 0;
    if (fill) u8g2.drawRBox(left + frame, top + frame, width - (2*frame), height - (2*frame), radius);
    else u8g2.drawRFrame(left, top, width, height, radius);
  }

  void print_text(String str, fonts f, box_alignment align, float pos) {
    u8g2.setFont(f.font);
    int x = 0;
    if(align == Center) x = left + 0.5 * (width - (f.width * str.length() - 1));
    else if(align == Left) x = left + 5;
    else if(align == Right) x = left + width - f.width * str.length() - 5;
    u8g2.setCursor(x, top + pos * height + f.height / 2);
    u8g2.print(str);
  }
};

// Initialize the boxes for the OLED
box top_left = {0, 0, 36, 10, 0, false};
box top = {top_left.width, 0, 56, 10, 0, false};
box top_right = {top.left + top.width, 0, top_left.width, 10, 0, false};
box mid_main = {0, top.height, 128, 34, 0, false};
box bot = {0, mid_main.top + mid_main.height, 128, 10, 0, false};

// Update the OLED display with the three boxes according to the given pages
void update_display(){
  u8g2.clearBuffer();
  mid_main.draw(false);

  if(new_page){
    if(millis() <= t_new_page + 750) mid_main.print_text(pages[current_page].page.title, font_m, Center, 0.5);
    else new_page = false;
  }

  if(!new_page){
    if(pages[current_page].page.is_value){
      if(current_page == 1){ //set profile page
        mid_main.print_text(String(*pages[current_page].page.value, 0), font_m, Center, 0.5);
        msg2display_bot = String(profile_temp[int(selected_profile)][1], 0) + ", " + String(profile_temp[int(selected_profile)][2], 0) + ", " +
              String(profile_temp[int(selected_profile)][3], 0) + ", " + String(profile_temp[int(selected_profile)][4], 0);
      }
      else mid_main.print_text(String(*pages[current_page].page.value, 1) + "C", font_s, Center, 0.5);
    }
    else{
      mid_main.print_text(("Cur Temp: " + String(current_temperature1) + " C"), font_s, Left, 0.21);
      mid_main.print_text(("Set Temp: " + String(pid_setpoint) + " C"), font_s, Left, 0.5);
      mid_main.print_text(("Progress: " + String(float(profile_counter)/3.0, 0) + " %"), font_s, Left, 0.8);
    }

    top_left.print_text(String(current_temperature1, 0) + "C", font_xs, Center, 0.5);
    top_right.print_text(String(current_temperature2, 0) + "C", font_xs, Center, 0.5);
    bot.print_text(msg2display_bot, font_xs, Center, 0.5);
    top.print_text(msg2display_top, font_xs, Center, 0.5);
  }
  u8g2.sendBuffer();
}



void setup() {
  Serial.begin(115200);
  Serial.println("start");

  pinMode(BTN1_PIN, INPUT);
  pinMode(BTN2_PIN, INPUT);
  pinMode(BTN3_PIN, INPUT);

  pinMode(CS_MAX1_PIN, OUTPUT);
  pinMode(CS_MAX2_PIN, OUTPUT);
  digitalWrite(CS_MAX1_PIN, LOW);
  digitalWrite(CS_MAX2_PIN, LOW);

  pinMode(SSR1_PIN, OUTPUT);
  pinMode(SSR2_PIN, OUTPUT);
  digitalWrite(SSR1_PIN, LOW);
  digitalWrite(SSR2_PIN, LOW);

  delay(100);
  FastLED.addLeds<APA102, APA102_SDI_PIN, APA102_CLK_PIN, BGR>(leds, NUM_LEDS);
  FastLED.setBrightness(100);
  delay(100);

  leds[0] = CRGB::Black;
  FastLED.show();

  pinMode(BUZZER_PIN, OUTPUT);
  digitalWrite(BUZZER_PIN, LOW);

  ledcSetup(PWMChannel, PWMFreq, PWMResolution);
  ledcAttachPin(BUZZER_PIN, PWMChannel);
  ledcWrite(PWMChannel, dutyCycle);

  ledcWrite(PWMChannel, 500);
  delay(200);
  ledcWrite(PWMChannel, 0); 

  preferences.begin("reflowprofiles", false);
  delay(100);
  read_all_profiles();


  Wire.begin(SDA_PIN, SCL_PIN);
  delay(100);
  u8g2.begin();
  delay(100);
  t_new_page = millis();
  update_display();
}

unsigned long t_thermo = millis();
unsigned long t_display = millis() + 100;
unsigned long t_pid_on = millis() + 400;
unsigned long t_start_reflow = millis();
unsigned long t_reflow_pid = millis() + 300;
unsigned long t_reflow_control = millis() + 500;

unsigned long t_const_pid = millis() + 300;
unsigned long t_const_control = millis() + 500;
unsigned long t_rampup = millis() + 600;
unsigned long t_profile_counter = millis() + 800;
unsigned long t_reflow_finish = millis() + 900;

void loop() {
  if(digitalRead(BTN1_PIN) == 1){
    leds[0] = CRGB::Blue;
    FastLED.show();
    delay(50);

    if(pages[current_page].page.is_value){
      if(current_page == 1) {
        if(selected_profile > 0)
          *pages[current_page].page.value = *pages[current_page].page.value - 1.0;
      }
      else *pages[current_page].page.value = *pages[current_page].page.value - 5.0;
    }
    update_display();

    unsigned long t_btn_pressed = millis();
    int wait_time_increase = 300;
    bool set_process = false;

    while (digitalRead(BTN1_PIN) == 1){
      if(millis() >= t_btn_pressed + wait_time_increase && !set_process){
        wait_time_increase = 80;
        t_btn_pressed = millis();

        if(pages[current_page].page.is_value){
          leds[0] = CRGB::Orange;
          FastLED.show();
          if(current_page == 1) {
            if(selected_profile > 0)
              *pages[current_page].page.value = *pages[current_page].page.value - 1.0;
          }
          else *pages[current_page].page.value = *pages[current_page].page.value - 5.0;
        }
        else{
          leds[0] = CRGB::Green;
          FastLED.show();
          if(current_page == 0) {
            running_reflow = !running_reflow;
            init_reflow = true;
            msg2display_top = running_reflow ? "Reflow" : "";
          }
          else if(current_page == 1){
           running_const = !running_const;
           init_const = true;
           msg2display_top = running_const ? "Const" : "";
          }
          set_process = true;
        }
        update_display();
      }
      delay(20);
    } 
    leds[0] = CRGB::Black;
    FastLED.show();
  }
  else if(digitalRead(BTN2_PIN) == 1){
    leds[0] = CRGB::Blue;
    FastLED.show();
    delay(50);

    if(pages[current_page].page.is_value){
      if(current_page == 1) {
        if(selected_profile < N_PROFILES-1)
          *pages[current_page].page.value = *pages[current_page].page.value + 1.0;
      }
      else *pages[current_page].page.value = *pages[current_page].page.value + 5.0;
    }

    update_display();
    unsigned long t_btn_pressed = millis();
    int wait_time_increase = 300;
    bool set_process = false;
    
    while (digitalRead(BTN2_PIN) == 1){
      if(millis() >= t_btn_pressed + wait_time_increase && !set_process){
        leds[0] = CRGB::Orange;
        FastLED.show();

        wait_time_increase = 80;
        t_btn_pressed = millis();

        if(pages[current_page].page.is_value){
          leds[0] = CRGB::Orange;
          FastLED.show();
          if(current_page == 1) {
            if(selected_profile < N_PROFILES-1)
              *pages[current_page].page.value = *pages[current_page].page.value + 1.0;
          }
          else *pages[current_page].page.value = *pages[current_page].page.value + 5.0;
        }
        else{
          leds[0] = CRGB::Green;
          FastLED.show();
          if(current_page == 0) {
            running_reflow = !running_reflow;
            init_reflow = true;
            msg2display_top = running_reflow ? "Reflow" : "";
          }
          else if(current_page == 1){
            running_const = !running_const;
            init_const = true;
            msg2display_top = running_const ? "Const" : "";
          }
          set_process = true;
        }
        update_display();
      }
      delay(20);
    } 
    leds[0] = CRGB::Black;
    FastLED.show();
  }
  else if(digitalRead(BTN3_PIN) == 1){
    leds[0] = CRGB::Blue;
    FastLED.show();
    delay(50);
    t_new_page = millis();
    new_page = true;
    current_page = (++current_page) % N_PAGES;
    msg2display_bot = "";
    update_display();

    unsigned long t_btn_pressed = millis();
    while (digitalRead(BTN3_PIN) == 1){
      if(millis() >= t_btn_pressed + 800){
        leds[0] = CRGB::Orange;
        FastLED.show();
      }
      delay(20);
    } 
    leds[0] = CRGB::Black;
    FastLED.show();
  }



  if(init_reflow){
    init_reflow = false;

    if(running_reflow){
      t_start_reflow = millis();
      profile_counter = 0;
      preheat_done = false;
      reflow_done = false;
      calculate_profile_individual();
      pid_setpoint = temp_reflow_individual[0];

      pid_reflow.SetOutputLimits(0, 500);
      pid_reflow.SetMode(AUTOMATIC);
      leds[0] = CRGB::Yellow;
      FastLED.show();
    }
    else{
      msg2display_bot = "";
      digitalWrite(SSR1_PIN, LOW);
      leds[0] = CRGB::Black;
      FastLED.show();
    }
  }


  if(running_reflow && !preheat_done){
    if(current_temperature1 < 30){
      if(millis() >= t_reflow_control + 500){
        t_reflow_control = millis();
        digitalWrite(SSR1_PIN, !digitalRead(SSR1_PIN));
        leds[0] = digitalRead(SSR1_PIN) ? CRGB::Blue : CRGB::Yellow; 
        FastLED.show();
        t_pid_on = millis();
      }
    }
    else{
      preheat_done = true;
      t_profile_counter = millis();
    }
  }


  while(reflow_done){
    if(millis() > t_reflow_finish + 1000){
      t_reflow_finish = millis();
      buzzer_state = !buzzer_state;
      ledcWrite(PWMChannel, buzzer_state ? 500 : 0);
      leds[0] = CRGB::Green; 
      FastLED.show();
      msg2display_bot = "Press any button!";
      update_display();
    }

    if(digitalRead(BTN1_PIN) == 1 || digitalRead(BTN2_PIN) == 1 || digitalRead(BTN3_PIN) == 1){
      reflow_done = false;
      ledcWrite(PWMChannel, 0);
      leds[0] = CRGB::Black; 
      FastLED.show();

      profile_counter = 0;
      pid_setpoint = temp_reflow_individual[0];
      
      while(digitalRead(BTN1_PIN) == 1 || digitalRead(BTN2_PIN) == 1 || digitalRead(BTN3_PIN) == 1){ 
        delay(100); 
      }
    }
  }

  

  if(running_reflow && preheat_done){
    int pid_error = int(pid_setpoint) - int(current_temperature1);

    if(millis() >= t_reflow_pid + 200){
      t_const_pid = millis();
      pid_setpoint = temp_reflow_individual[profile_counter];
      pid_input = current_temperature1;
      pid_reflow.Compute();
      msg2display_bot = String(pid_output, 0) + ", " + String(pid_setpoint, 0) + ", " + String(pid_error) + ", " + String(profile_counter) + "/300";// + ", " + String(window_start_time);
    }

    if(millis() >= t_reflow_control + 500){
      t_reflow_control = millis();
      
      if(pid_output > 50){
        digitalWrite(SSR1_PIN, HIGH);
        leds[0] = CRGB::Red;
        FastLED.show();
        t_pid_on = millis();
      }
    }

    if(millis() > t_pid_on + pid_output && digitalRead(SSR1_PIN)){
      digitalWrite(SSR1_PIN, LOW);
      leds[0] = CRGB::Yellow;
      FastLED.show();
    }

    if(millis() >= t_profile_counter + 1000){
      t_profile_counter += 1000;
      profile_counter++;
      if(profile_counter > 300){
        ledcWrite(PWMChannel, 500);
        msg2display_top = "";
        buzzer_state = true;
        running_reflow = false;
        t_reflow_finish = millis();
        reflow_done = true;
        digitalWrite(SSR1_PIN, LOW);
        leds[0] = CRGB::Yellow;
        FastLED.show();
      }
    }
  }


  if(init_const){
    init_const = false;

    if(running_const){
      pid_setpoint = temperature_setpoint_const;
      rampup_const = true;
      pid.SetOutputLimits(0, 1000);
      pid.SetMode(AUTOMATIC);
      leds[0] = CRGB::Yellow;
      FastLED.show();
    }
    else{
      msg2display_bot = "";
      digitalWrite(SSR1_PIN, LOW);
      leds[0] = CRGB::Black;
      FastLED.show();
    }
  }


  if(running_const){
    int pid_error = int(pid_setpoint) - int(current_temperature1);

    if(pid_error < 5 && pid_error > -5 && rampup_const_close){
      rampup_const_close = false;
      t_rampup = millis();
    }

    if(millis() >= t_const_pid + 200){
      t_const_pid = millis();
      pid_input = current_temperature1;
      pid.Compute();
      msg2display_bot = String(pid_output, 0) + ", " + String(pid_error, 0) + ", " + String(rampup_const, 0);// + ", " + String(window_start_time);
    }

    if(millis() >= t_const_control + 2000){
      t_const_control = millis();
      
      if(rampup_const){
        if(pid_error < 0){
          rampup_const = false;
          pid.SetOutputLimits(0, 300);
          ledcWrite(PWMChannel, 500);
          delay(200);
          ledcWrite(PWMChannel, 0); 
        }
        else if(pid_error < 10){
          pid.SetOutputLimits(0, 150);
        }
        else if(pid_error < 20){
          pid.SetOutputLimits(0, 300);
        }

        if(millis() > t_rampup + 10000 && !rampup_const_close){
          rampup_const = false;
          pid.SetOutputLimits(0, 300);

          ledcWrite(PWMChannel, 500);
          delay(200);
          ledcWrite(PWMChannel, 0); 
        }
      }
      
      if(pid_output > 50){
        digitalWrite(SSR1_PIN, HIGH);
        leds[0] = CRGB::Red;
        FastLED.show();
        t_pid_on = millis();
      }
    }

    if(millis() > t_pid_on + pid_output && digitalRead(SSR1_PIN)){
      digitalWrite(SSR1_PIN, LOW);
      leds[0] = CRGB::Yellow;
      FastLED.show();
    }
  }



  if(millis() >= t_display + 500){
    t_display = millis();
    update_display();
  }

  
  if(millis() >= t_thermo + 200){
    t_thermo = millis();
    current_temperature1 = thermocouple1.readCelsius();//random(50, 300);//
    current_temperature2 = thermocouple2.readCelsius();//random(50, 300);//thermocouple2.readCelsius();
    val1 = float(random(50,300));
  }
}

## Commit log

2022-02-01 added PCB files and schematics
    [reflow_controller_v2.brd, reflow_controller_v2.sch]
2022-02-23 updated docs and added cases + images
    [bot_spacer.stl, hv_case.stl]
2022-03-12 updated schematics and code
    [reflow_controller_v2.sch]
2022-04-21 added gerber files
    [copper_bottom.gbr, copper_top.gbr, drill_1_16.xln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]
2022-04-21 added .sch and .brd for eagle7.x
    [reflow_controller_v2_eagle7.brd, reflow_controller_v2_eagle7.sch]
2022-08-28 Added file for component sourcing
    Component sources for most parts. Some connectors could not be found
2022-12-27 Create BOM CSV with annotations
2023-11-21 added pdf schematics
2023-11-21 added 3d models
    [rc_acrylic_front.stl, rc_base1.stl, rc_base2.stl]

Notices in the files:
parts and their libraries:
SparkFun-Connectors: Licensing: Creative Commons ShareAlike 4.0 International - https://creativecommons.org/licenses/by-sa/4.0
